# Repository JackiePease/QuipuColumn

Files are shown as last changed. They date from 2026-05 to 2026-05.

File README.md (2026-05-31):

# QuipuColumn

This was a project I did for [Civic Data Cooperative's Fesival of Data](https://civicdatacooperative.com/festival-of-data/) in Liverpool, an interactive 3-day event, which took place on 5,6,7 February 2026.

With children from Lawrence Primary School, and volunteers from Liverpool University, I made a Quipu Column with knotted cords and LED strips hanging down from a central column made from a clear HIPS pipe and an Armadillo bike lane separator. 

The LED strips were fed through the pipe to a disk at the bottom and controlled by 3 [MCQN Ltd My Bikes Got LED boards](https://github.com/mcqn/my-bikes-got-led).

The column was a bit unstable at the event, so I bought a large parasol stand to replace the Armadillo. Unfortunately although this said it took a 50mm pole, it's actually designed for an American measurement (equivalent to 48.3mm). I resized the 3D print designs to fit, and also made some changes to the design (e.g. not having the LEDs starting from higher than the cords, cutting larger parts on the laser cutter as the big 3D printer at DoES Liverpool was out of action, and having the LEDs going up the outside of the pipe).

In the end I didn't use the LEDs when showing this at Wirral MakeFest, but the option is still there.

## Files in this Repository
### 3D Printing and Laser Cutting Files (all designed in OnShape)

Small 3D printed Maquette

#### For 50mm pipe

Corner Part - corner for laser cut hexagon edge shape DXF<br>
Hold Bar - unused 3D printed side part for ropes to go attach to at the base (difficult to print)<br>
New Top Part(part that fits over the top of the pipe)<br>
New Wheel - larger diameter 3D printed part that attaches to new top part<br>
Side part - Hexagon edge parts<br>
<br>

#### For 48.3mm pipe

Base Clip - Attached to base - ropes feed through and are attached underneath<br>
 - 
Base clips for LEDs (not currently used)<br>
Corner support - 2 of these are used to attach to previously unsupported corners of the large hexagon (in this version its screwed on to the parasol stand in 2 places)<br>
MDF electric wheel - allows MCQN My Bike's Got LED boards to be attached at the base with wires or unlit LED strips going up through the pipe<br>
Plugs - Go through holes in the top part to allow cords to be attached with key rings<br>
Separator - Attaches to the cord to separate 10s and units etc.<br>
10mm separator<br>
12mm separator<br>
Top part
Top part without side holes<br>
Wheel part for top<br>

### Photos

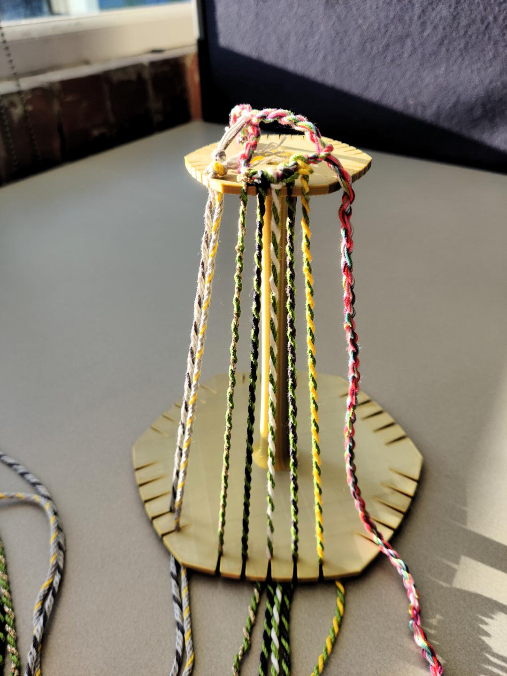
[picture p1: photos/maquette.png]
Small 3D printed Maquette


#### Original Quipu Column at the Festival

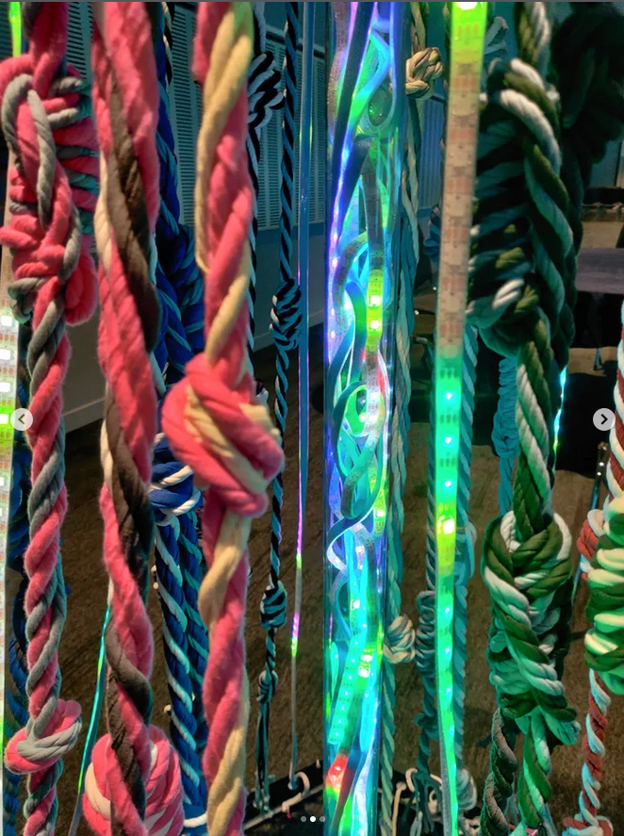
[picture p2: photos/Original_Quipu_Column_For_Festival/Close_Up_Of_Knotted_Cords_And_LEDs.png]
Close up of knotted cords/ropes

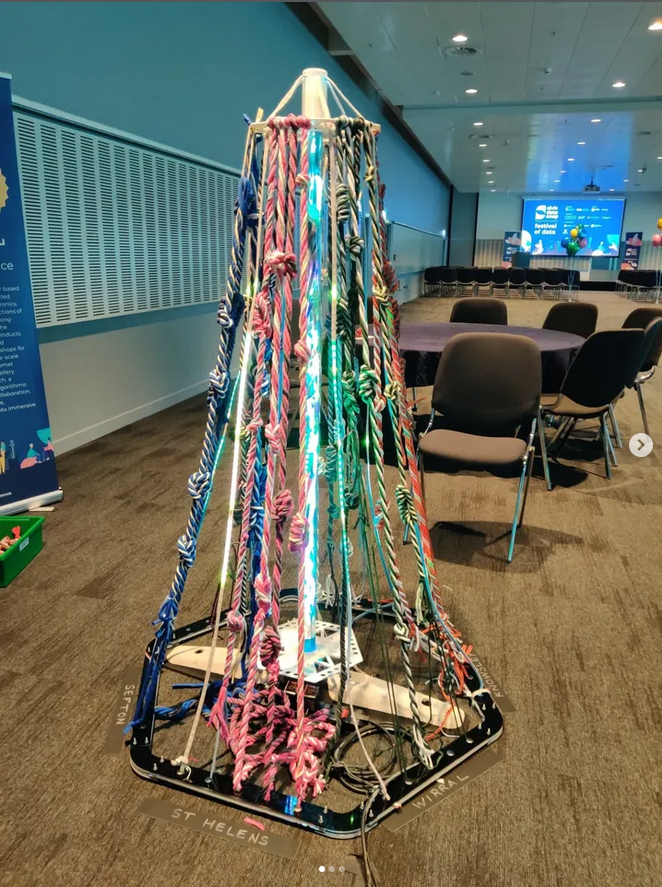
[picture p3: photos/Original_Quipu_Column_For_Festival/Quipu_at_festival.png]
Quipu in the main room at the Festival

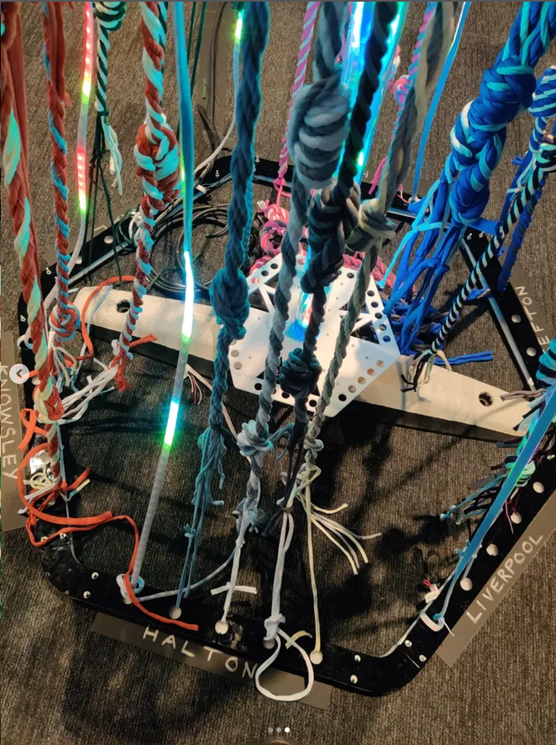
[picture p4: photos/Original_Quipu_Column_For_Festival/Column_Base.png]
Base of the column


#### Quipu Column as rebuilt for Wirral MakeFest

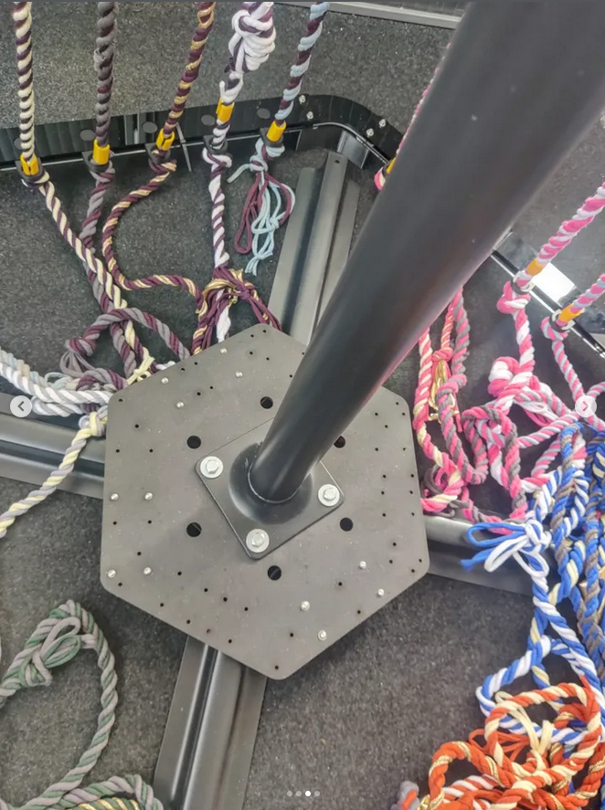
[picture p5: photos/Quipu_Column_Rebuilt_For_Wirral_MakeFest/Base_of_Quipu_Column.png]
Base of Quipu Column

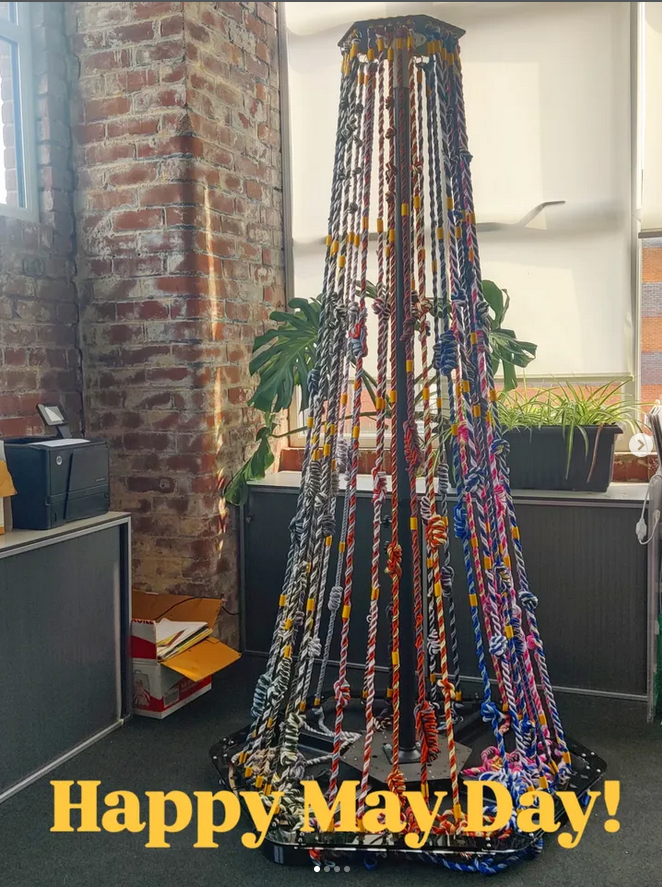
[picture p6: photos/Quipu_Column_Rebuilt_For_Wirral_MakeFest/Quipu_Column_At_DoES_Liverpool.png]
Quipu Column at DoES Liverpool

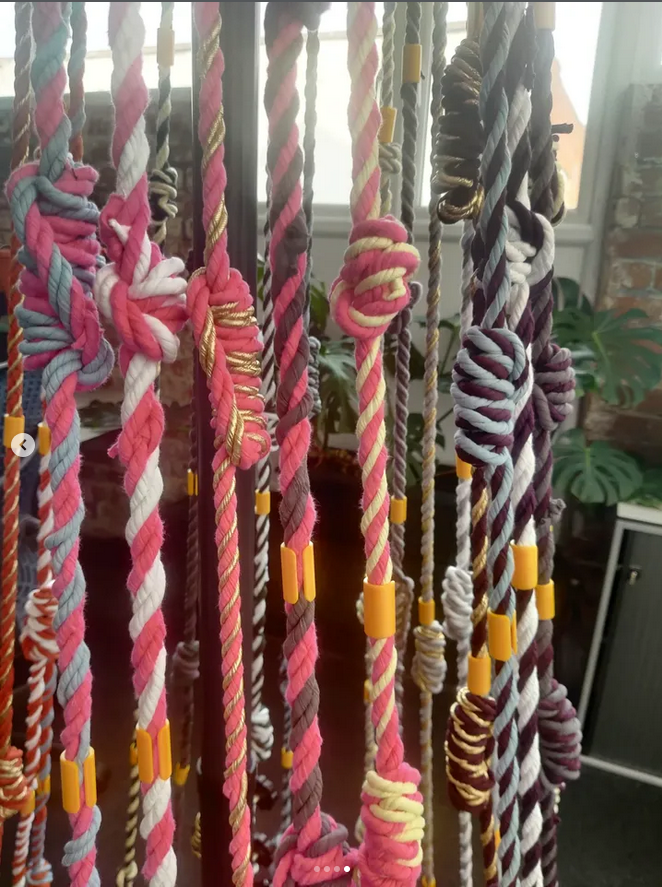
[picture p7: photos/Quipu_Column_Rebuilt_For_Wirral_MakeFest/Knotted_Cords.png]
Close up of knotted cords

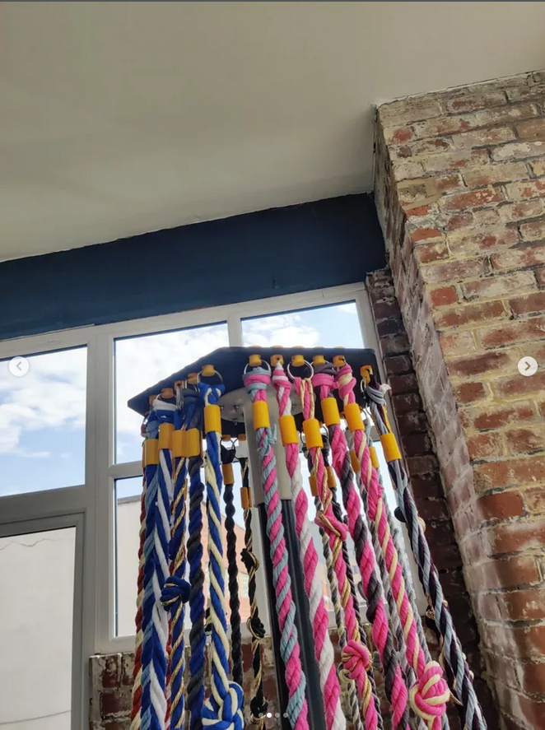
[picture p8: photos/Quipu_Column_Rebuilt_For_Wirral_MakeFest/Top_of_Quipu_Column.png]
Top of column showing cord attachment


### Code

Arduino code for the LEDs on the original column<br>
It was difficult to code WLED to show different numbers of lit up LEDs in different segments, and I didn't need the Wifi part, so I ended up using the boards as Arduinos. It may be simpler with the new version of WLED - to be checked. I originally had the LEDs moving, but they needed to be static for readability. 
As the room was quite dark, the cords were hard to read when the LEDs were on full brightness - the brightness had to be reduced a lot to allow both to be read.

### Documents

Example numbers converted to Quipu cords
Key for Knots and LEDs

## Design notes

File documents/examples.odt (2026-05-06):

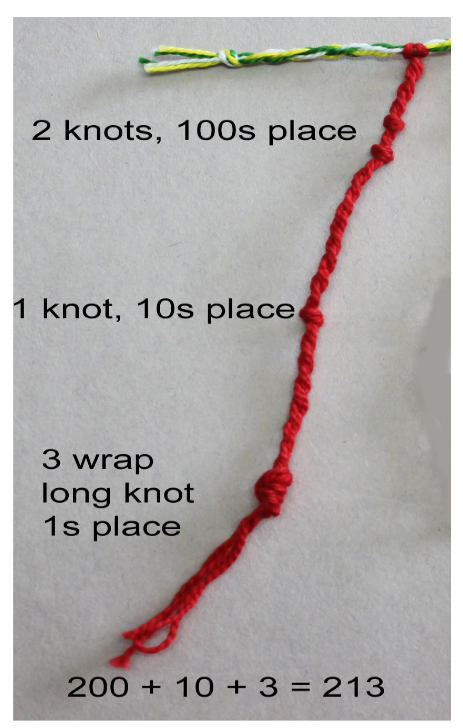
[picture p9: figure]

# Coding the LED strip

We can’t do different types of knot in the LED strip (well not using electricity anyway), so I’ve just used individual LEDs e.g. 5 LEDs in the tens position = 50. There is one yellow light to separate 10s from ones, ones from 1st decimal place, etc. and 2 yellow lights at the end.

The colour of the lights represents the area e.g. Purple for Liverpool, Green for Wirral

Example:

Y | | | | | * | * | * | * | * | Y | | | | | | | * | * | * | Y | | | | | | * | * | * | * | Y | | | | | | | * | * | * | Y | Y

- Yellow Light
- 5 lights in tens positions = 50
- Yellow Light
- 3 lights in ones positions = 3
- Yellow Light
- 4 lights in first decimal place positions = 0.4
- Yellow Light
- 3 lights in second decimal place positions = 0.03

So number represented is 53.43

Originally I had the data moving along the LED strips, but this made it too difficult to read. I’ve changed it so there is one static copy of the data on the outside part of the strip, and 2 moving copies within the column (the LEDs inside the column don’t need to be read – they represent the digital activity that the non-included households are missing out on, and that they can’t decipher at the moment).

The Data

The data being shown by the LED strips is the percentage of households in the City of Liverpool, and the 5 boroughs of the Liverpool City Region (Halton, Knowsley, St Helens, Sefton, Wirral), which don’t have “the minimum basket of digital goods, services, and skills that households need to live and participate in the digital world” (you can find out more at https://mdls.org.uk/).

Area | Average of Percent Not Meeting Full MDLS (Equipment and skills)
Halton | 40.63%
Knowsley | 40.55%
Liverpool | 38.93%
Sefton | 39.68%
St.Helens | 39.98%
Wirral | 39.98%
Grand Total | 39.71%

The Quipu strings show some of the equipment elements that make up that data.

Row Labels | Average of Overall percent not adequate equipment | Average of Percent not adequate BB | Average of Percent not adequate Smart TV | Average of Percent not adequate number of Large Screen Devices | Average of Percent significantly below MDLS equipment needs
Halton | 12.34% | 5.85% | 1.83% | 2.64% | 2.02%
Knowsley | 12.51% | 6.03% | 1.79% | 2.60% | 2.08%
Liverpool | 14.31% | 5.78% | 2.64% | 3.64% | 2.25%
Sefton | 13.32% | 7.63% | 1.57% | 2.43% | 1.68%
St.Helens | 12.50% | 7.12% | 1.45% | 2.46% | 1.47%
Wirral | 13.29% | 7.89% | 1.40% | 2.53% | 1.48%
Grand Total | 13.36% | 6.76% | 1.89% | 2.86% | 1.86%

The cords are made of 2 colours, one represents the area, and one represents the data being shown. The support structure has 6 sides – one for each area.

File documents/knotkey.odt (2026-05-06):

Knot Key (3 Types)

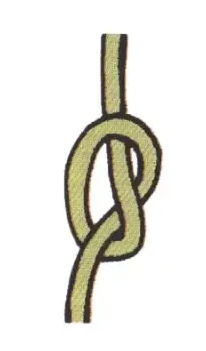
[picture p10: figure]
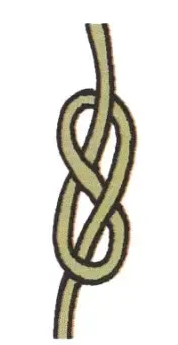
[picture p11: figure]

1) Single Knot (for tens, hundreds, thousands) Used in groups. Example: 4 tens = 4 single knots in the tens zone. | 2) Figure-of-Eight Knot (for 1 in the ones place) 1 one = 1 figure-of-eight knot

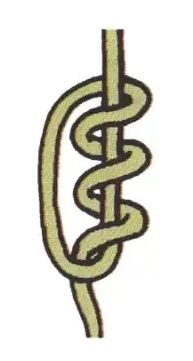
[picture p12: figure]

3) Long Knot (for 2–9 in the ones place) A long knot has loops. Example: 6 ones = long knot with 6 loops | Rule for Zero If a place value digit is 0, leave that place blank. Places after the Decimal Point I couldn’t find any examples of recording decimal places, so have used the same format as for ones i.e. figure-of-eight and long knots. Separators Sometimes it’s difficult to work out what place a knot is in, especially in a number containing zeros. Although the Inca Empire’s Quipucamayocs were obviously able to do without (possibly due to more accurate placing of the knots), I decided to mark the boundaries between place values (and the start and end of each cord) with yellow 3D printed separat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

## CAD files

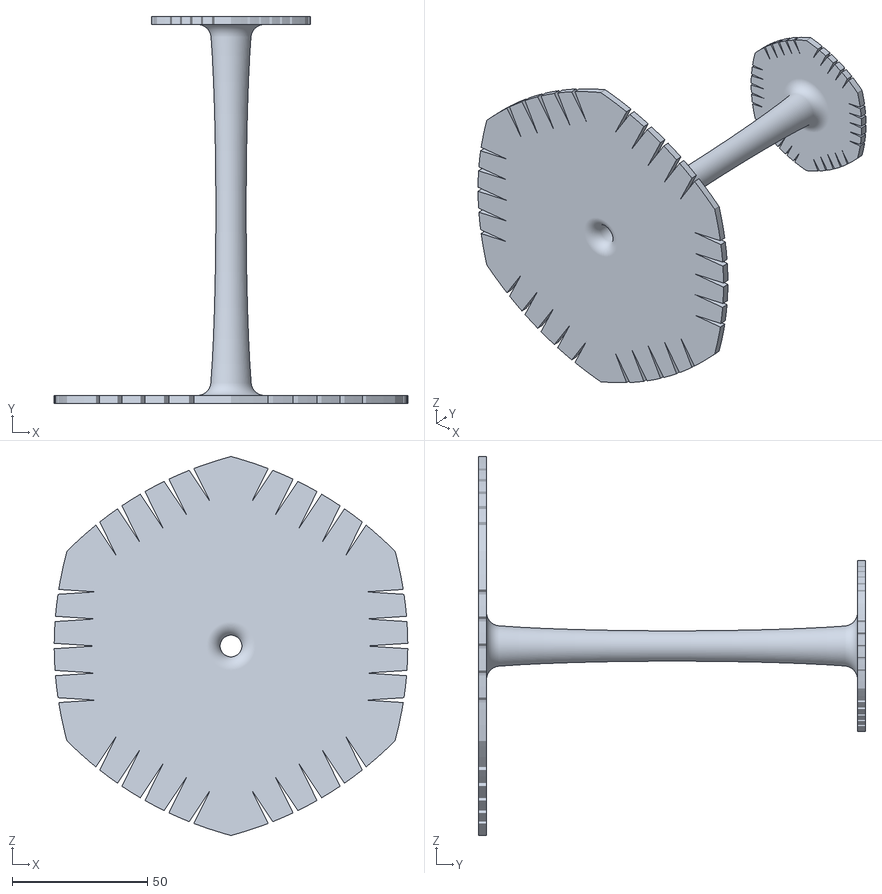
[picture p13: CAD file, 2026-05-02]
3D_printing_and_laser_cutting_files/6_boroughs.stl
130.6 x 143.0 x 140.0

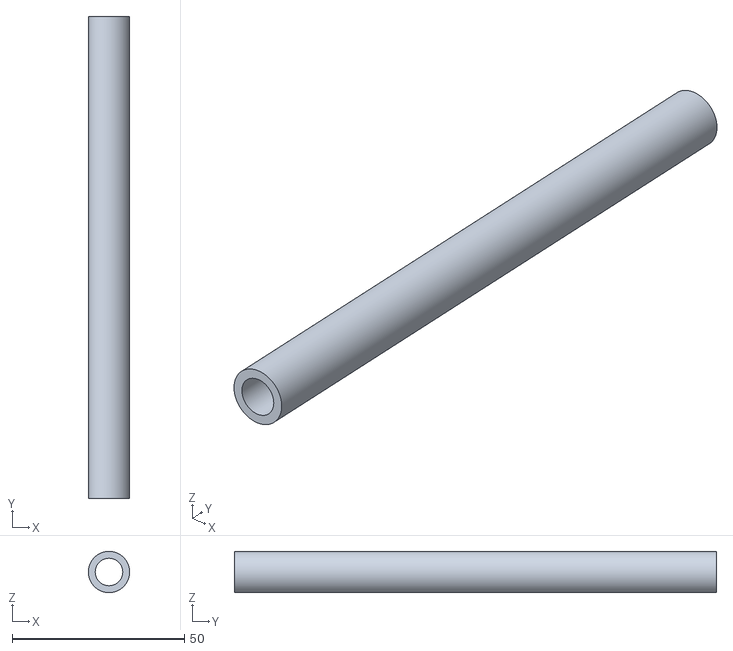
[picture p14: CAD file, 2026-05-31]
3D_printing_and_laser_cutting_files/DHMakes/column.stl
12.0 x 140.0 x 12.0

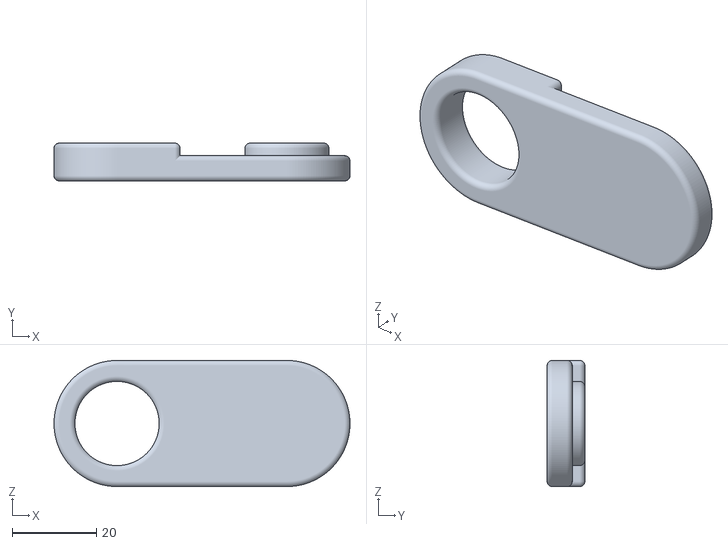
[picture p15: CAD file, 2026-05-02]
3D_printing_and_laser_cutting_files/for_48point3mm_pipe/base_clip.stl
70.4 x 9.00 x 30.0

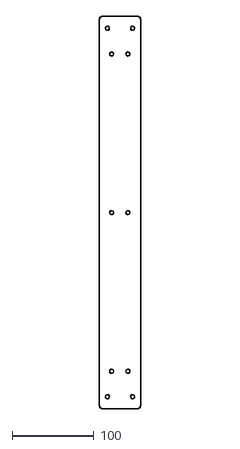
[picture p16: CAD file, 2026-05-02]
3D_printing_and_laser_cutting_files/for_50mm_pipe/side_part.dxf
50.8 x 480.0

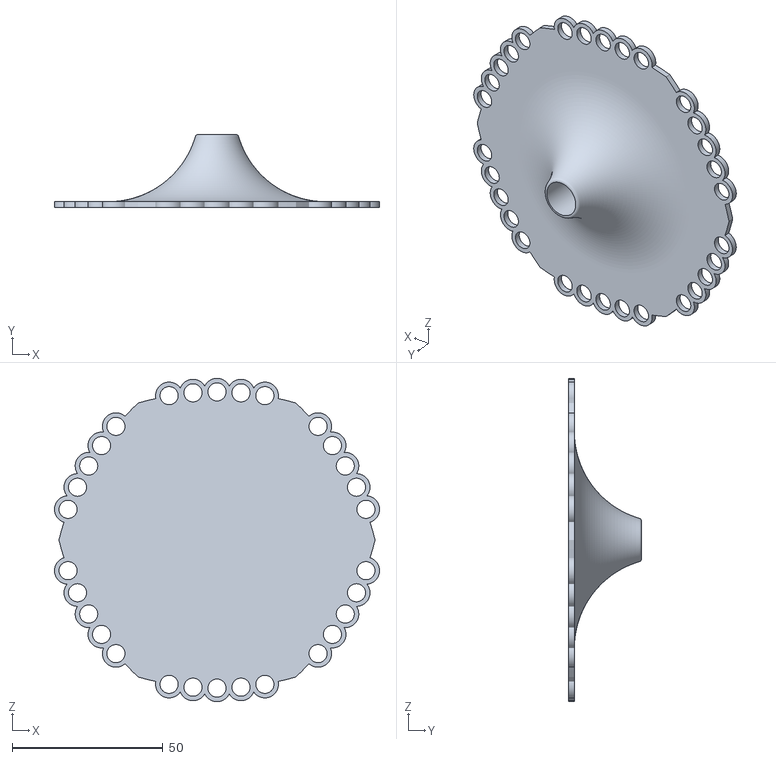
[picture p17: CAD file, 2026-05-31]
3D_printing_and_laser_cutting_files/DHMakes/top_lace_plate.stl
107.9 x 24.3 x 107.4

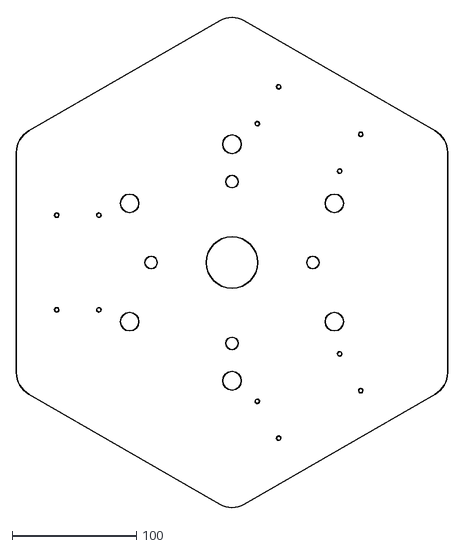
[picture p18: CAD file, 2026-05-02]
3D_printing_and_laser_cutting_files/for_48point3mm_pipe/mdf_electric_wheel.dxf
346.4 x 395.6

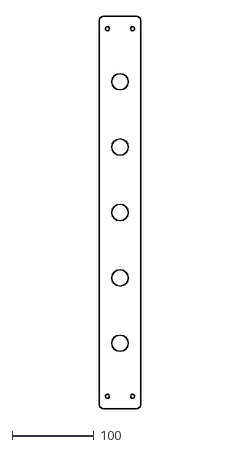
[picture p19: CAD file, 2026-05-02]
3D_printing_and_laser_cutting_files/for_50mm_pipe/new_side_part.dxf
50.8 x 480.0

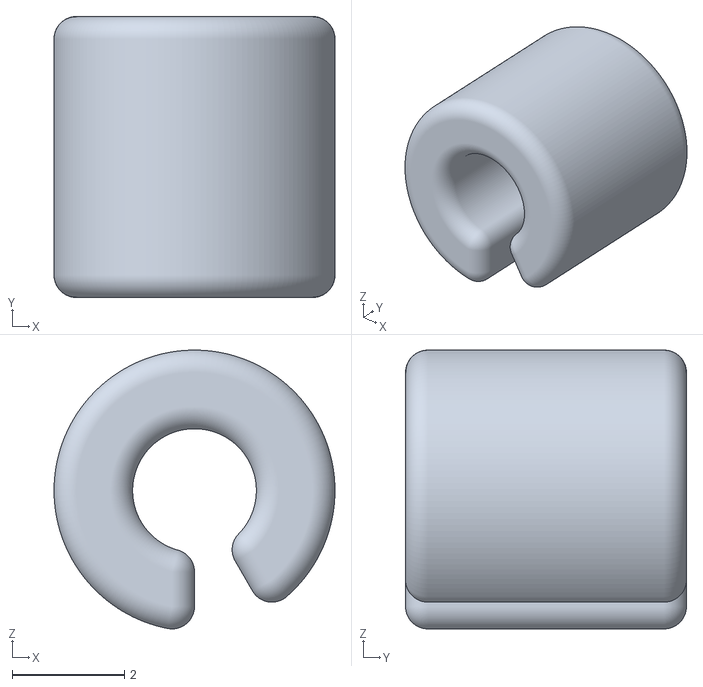
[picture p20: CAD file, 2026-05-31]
3D_printing_and_laser_cutting_files/DHMakes/beads.stl
5.00 x 5.00 x 4.96

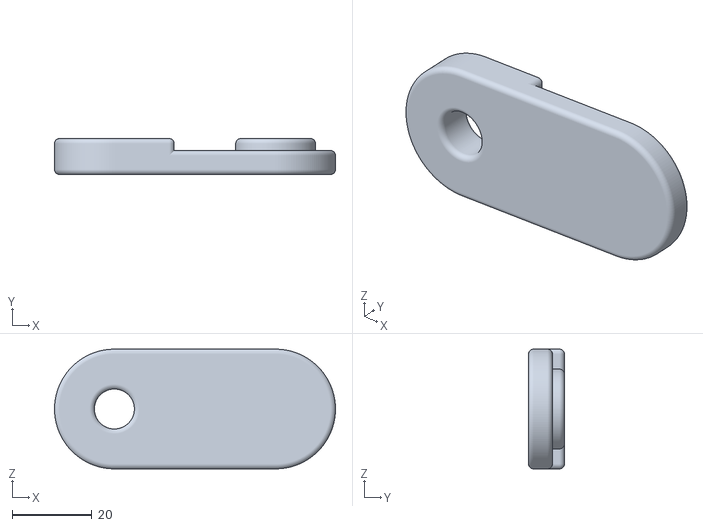
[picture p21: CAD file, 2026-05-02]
3D_printing_and_laser_cutting_files/for_48point3mm_pipe/base_clip_LEDs.stl
70.4 x 9.00 x 30.0

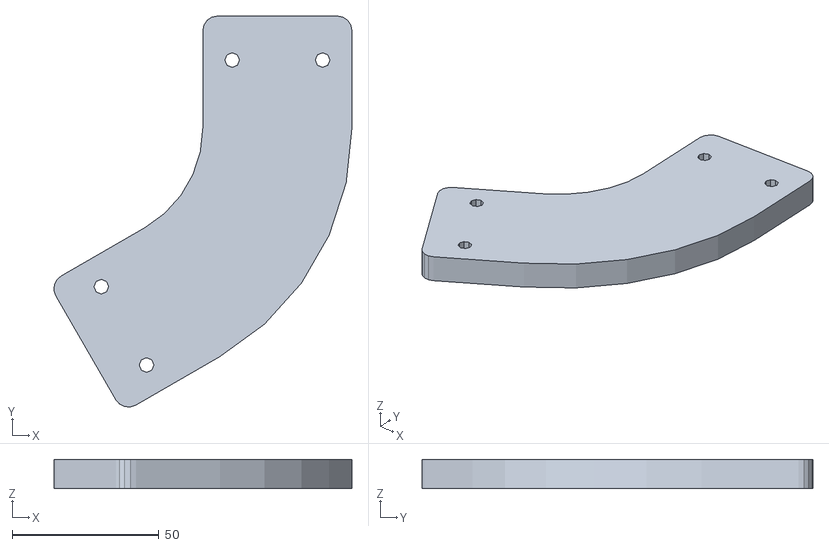
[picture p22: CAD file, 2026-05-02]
3D_printing_and_laser_cutting_files/for_50mm_pipe/corner_part.stl
101.5 x 133.1 x 10.0

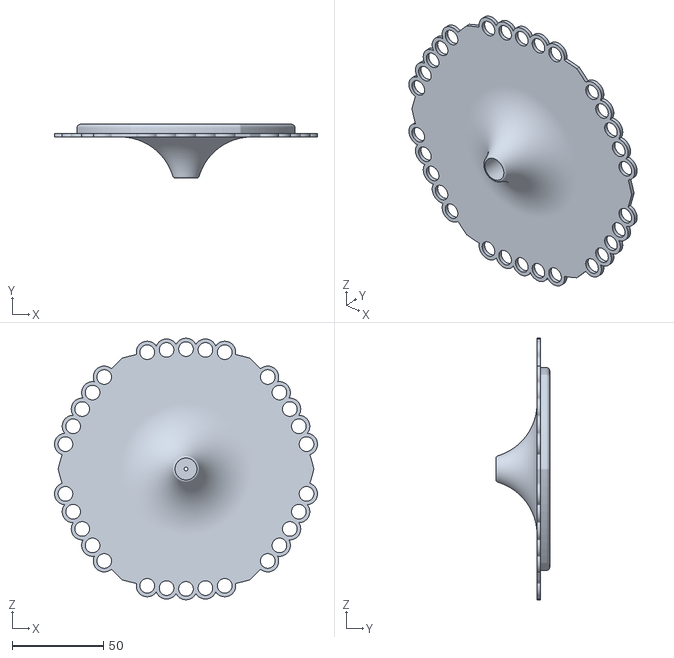
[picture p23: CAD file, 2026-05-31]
3D_printing_and_laser_cutting_files/DHMakes/bottom_lace_plate.stl
143.9 x 29.3 x 143.1

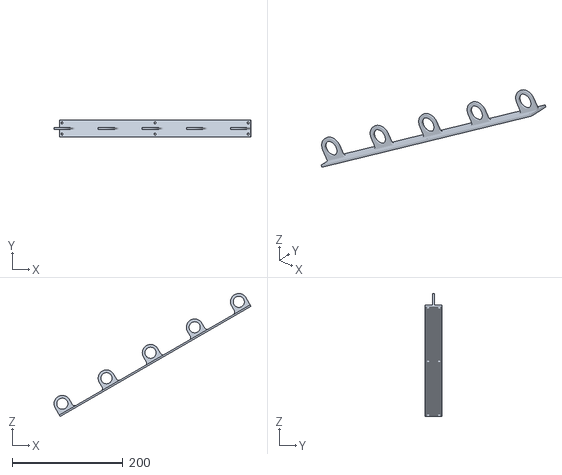
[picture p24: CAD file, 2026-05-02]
3D_printing_and_laser_cutting_files/for_50mm_pipe/hold_bar.stl
355.3 x 30.0 x 221.9

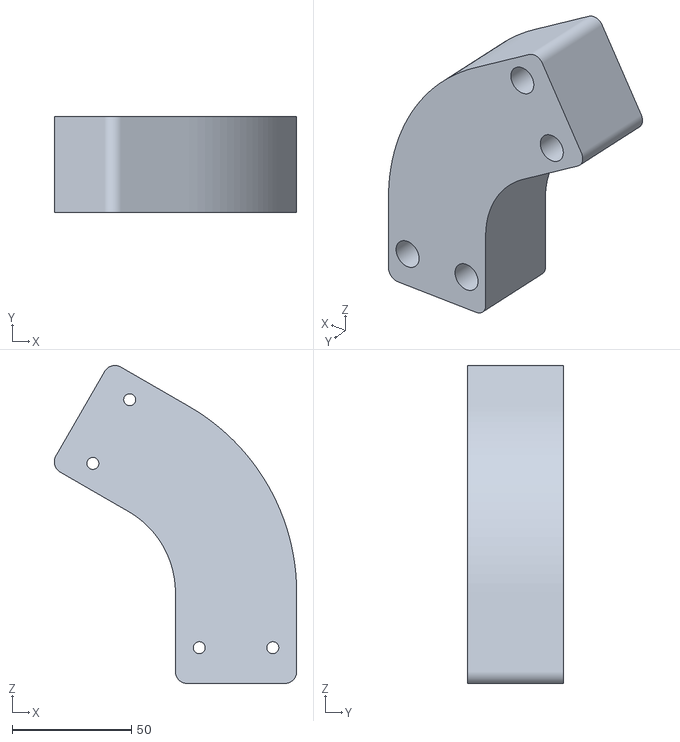
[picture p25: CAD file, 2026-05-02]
3D_printing_and_laser_cutting_files/for_48point3mm_pipe/corner_support.stl
101.5 x 40.0 x 133.2

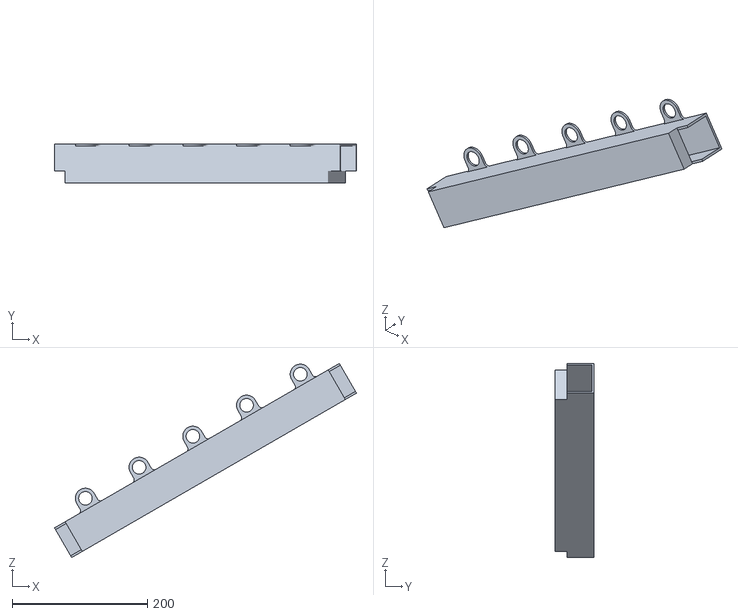
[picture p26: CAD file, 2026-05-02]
3D_printing_and_laser_cutting_files/for_50mm_pipe/side.stl
447.4 x 57.5 x 287.6

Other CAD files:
3D_printing_and_laser_cutting_files/for_50mm_pipe/corner.stl
3D_printing_and_laser_cutting_files/for_50mm_pipe/corner_part.dxf

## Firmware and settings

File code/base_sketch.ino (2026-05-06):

#include <Adafruit_NeoPixel.h>

// ============================================================
//                    SELECT YOUR BOARD HERE
// ============================================================
// 1 = Board 1 (Sefton + Liverpool)
// 2 = Board 2 (Knowsley + Halton)
// 3 = Board 3 (St Helens + Wirral)
#define BOARD_ID 2
// ============================================================

#define NUM_LEDS 300
#define PIN_5 5
#define PIN_6 6

Adafruit_NeoPixel strip5(NUM_LEDS, PIN_5, NEO_GRB + NEO_KHZ800);
Adafruit_NeoPixel strip6(NUM_LEDS, PIN_6, NEO_GRB + NEO_KHZ800);

// -------------------- Brightness --------------------
// const uint8_t BRIGHTNESS = 128; // ~50%
const uint8_t BRIGHTNESS = 255; // 100%
// -------------------- Pattern Rules --------------------
const uint8_t DIGIT_BLOCK = 10;
const uint8_t DIGITS = 4;
const uint8_t END_MARKERS = 2;   // 2 yellow lights at end

const uint16_t PATTERN_LENGTH =
  (DIGITS * (1 + DIGIT_BLOCK)) + END_MARKERS; // 46

// -------------------- Layout Rules --------------------
// Normal layout
const uint16_t MOVE_START_NORMAL = 0;
const uint16_t MOVE_LEN_NORMAL   = 119;

const uint16_t STATIC_START_NORMAL = 180;
const uint16_t STATIC_LEN_NORMAL   = 120;

// Special layout (Halton broken pixels)
const uint16_t MOVE_START_SPECIAL = 0;
const uint16_t MOVE_LEN_SPECIAL   = 145;

const uint16_t STATIC_START_SPECIAL = 145;
const uint16_t STATIC_LEN_SPECIAL   = 121;

// -------------------- Moving copies --------------------
const uint8_t MOVING_COPIES = 2;

// -------------------- Speed --------------------
const uint16_t FRAME_DELAY_MS = 140;

// -------------------- Movement offsets --------------------
uint16_t movingOffset5 = 0;
uint16_t movingOffset6 = 0;

// -------------------- Separator colour --------------------
uint32_t MARKER;  // bright yellow

// ============================================================
//                 DRAW PATTERN (BACKWARDS)
// ============================================================
void drawPercentageBackwardsInRegion(Adafruit_NeoPixel &strip,
                                     float percentage,
                                     uint32_t colour,
                                     uint16_t regionStart,
                                     uint16_t regionLen,
                                     int16_t endOffsetFromRegionEnd) {
  uint8_t tens  = ((int)(percentage / 10)) % 10;
  uint8_t units = ((int)(percentage)) % 10;
  uint8_t dec1  = ((int)(percentage * 10)) % 10;
  uint8_t dec2  = ((int)(percentage * 100)) % 10;

  uint8_t digits[4] = {tens, units, dec1, dec2};

  int32_t regionEnd = regionStart + regionLen - 1;
  int32_t idx = regionEnd - endOffsetFromRegionEnd;

  auto setInRegion = [&](int32_t absolutePixel, uint32_t c) {
    if (absolutePixel < (int32_t)regionStart) return;
    if (absolutePixel > (int32_t)regionEnd) return;
    strip.setPixelColor((uint16_t)absolutePixel, c);
  };

  // 2 yellow lights at end
  for (uint8_t i = 0; i < END_MARKERS; i++) {
    setInRegion(idx--, MARKER);
  }

  // digits reversed so it reads correctly from the end upward
  for (int d = 3; d >= 0; d--) {
    for (uint8_t i = 0; i < DIGIT_BLOCK; i++) {
      setInRegion(idx--, (i < digits[d]) ? colour : 0);
    }
    setInRegion(idx--, MARKER); // separator
  }
}

// ============================================================
//              DRAW MOVING PATTERN (FORWARDS)
// ============================================================
void drawPercentageMovingInRegion(Adafruit_NeoPixel &strip,
                                  float percentage,
                                  uint32_t colour,
                                  uint16_t regionStart,
                                  uint16_t regionLen,
                                  uint16_t offset) {
  uint8_t tens  = ((int)(percentage / 10)) % 10;
  uint8_t units = ((int)(percentage)) % 10;
  uint8_t dec1  = ((int)(percentage * 10)) % 10;
  uint8_t dec2  = ((int)(percentage * 100)) % 10;

  uint8_t digits[4] = {tens, units, dec1, dec2};

  uint16_t idx = offset % regionLen;

  auto setWrapped = [&](uint16_t localIndex, uint32_t c) {
    strip.setPixelColor(regionStart + (localIndex % regionLen), c);
  };

  for (uint8_t d = 0; d < 4; d++) {
    setWrapped(idx++, MARKER);

    for (uint8_t i = 0; i < DIGIT_BLOCK; i++) {
      setWrapped(idx++, (i < digits[d]) ? colour : 0);
    }
  }

  // 2 yellow lights at end
  setWrapped(idx++, MARKER);
  setWrapped(idx++, MARKER);
}

// ============================================================
//                DRAW WHOLE STRIP (ONE AREA)
// ============================================================
void drawArea(Adafruit_NeoPixel &strip,
              float percentage,
              uint32_t colour,
              bool useSpecialMap,
              uint16_t movingOffset) {
  strip.clear();

  uint16_t moveStart, moveLen, staticStart, staticLen;

  if (useSpecialMap) {
    moveStart = MOVE_START_SPECIAL;
    moveLen   = MOVE_LEN_SPECIAL;
    staticStart = STATIC_START_SPECIAL;
    staticLen   = STATIC_LEN_SPECIAL;
  } else {
    moveStart = MOVE_START_NORMAL;
    moveLen   = MOVE_LEN_NORMAL;
    staticStart = STATIC_START_NORMAL;
    staticLen   = STATIC_LEN_NORMAL;
  }

  // ---- Moving pattern (2 copies) ----
  uint16_t spacing = moveLen / MOVING_COPIES;

  for (uint8_t i = 0; i < MOVING_COPIES; i++) {
    drawPercentageMovingInRegion(strip, percentage, colour,
                                 moveStart, moveLen,
                                 movingOffset + (i * spacing));
  }

  // ---- Stationary centered pattern ----
  int16_t endOffset = 0;
  if (staticLen > PATTERN_LENGTH) {
    endOffset = (staticLen - PATTERN_LENGTH) / 2;
  }

  drawPercentageBackwardsInRegion(strip, percentage, colour,
                                  staticStart, staticLen, endOffset);
}

// ============================================================
//                           SETUP
// ============================================================
void setup() {
  strip5.begin();
  strip6.begin();

  strip5.setBrightness(BRIGHTNESS);
  strip6.setBrightness(BRIGHTNESS);

  strip5.clear();
  strip6.clear();

  strip5.show();
  strip6.show();

  // Bright yellow markers (instead of white)
  MARKER = strip5.Color(255, 255, 0);
}

// ============================================================
//                            LOOP
// ============================================================
void loop() {

  float pct5 = 0.0, pct6 = 0.0;
  uint32_t col5 = 0, col6 = 0;

  bool specialMapPin5 = false;
  bool specialMapPin6 = false;

#if BOARD_ID == 1
  // Board 1
  // Pin 5: Sefton (bright sky blue)
  // Pin 6: Liverpool (purple)
  pct5 = 39.68; col5 = strip5.Color(0, 180, 255);     // Sefton
  pct6 = 38.93; col6 = strip6.Color(150, 0, 255);     // Liverpool

#elif BOARD_ID == 2
  // Board 2
  // Pin 5: Knowsley (bright red)
  // Pin 6: Halton (light grey, special mapping)
  pct5 = 40.55; col5 = strip5.Color(255, 0, 0);       // Knowsley
  pct6 = 40.63; col6 = strip6.Color(200, 200, 200);   // Halton (light grey)

  specialMapPin6 = true;

#elif BOARD_ID == 3
  // Board 3
  // Pin 5: St Helens (dusky rose)
  // Pin 6: Wirral (bottle green)
  pct5 = 39.98; col5 = strip5.Color(200, 90, 110);    // St Helens
  pct6 = 39.98; col6 = strip6.Color(0, 90, 30);       // Wirral

#else
#error "Invalid BOARD_ID - set it to 1, 2, or 3"
#endif

  // Draw both strips
  drawArea(strip5, pct5, col5, specialMapPin5, movingOffset5);
  drawArea(strip6, pct6, col6, specialMapPin6, movingOffset6);

  strip5.show();
  strip6.show();

  // Update offsets
  uint16_t len5 = specialMapPin5 ? MOVE_LEN_SPECIAL : MOVE_LEN_NORMAL;
  uint16_t len6 = specialMapPin6 ? MOVE_LEN_SPECIAL : MOVE_LEN_NORMAL;

  movingOffset5 = (movingOffset5 + 1) % len5;
  movingOffset6 = (movingOffset6 + 1) % len6;

  delay(FRAME_DELAY_MS);
}

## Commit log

2026-05-02 Added stl files and photos
    [6_boroughs.stl, base_clip.stl, base_clip_10mm.stl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]
2026-05-06 Renamed folders, added code
    [6_boroughs.stl, base_clip.stl, base_clip_10mm.stl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]
2026-05-06 Added more descriptions etc.
    [6_boroughs.stl, base_clip.stl, base_clip_10mm.stl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]
2026-05-31 Added 3D printed parts for mini (150mm)
    [beads.stl, bottom_lace_plate.stl, column.stl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]
